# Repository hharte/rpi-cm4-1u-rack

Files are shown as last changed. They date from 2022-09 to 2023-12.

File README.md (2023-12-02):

# Raspberry Pi Compute Module 4 1U Rackmount Enclosure

# Introduction

This project consists of a [Mini-ITX](https://en.wikipedia.org/wiki/Mini-ITX) adapter and I/O plate to mount the [Raspberry Pi Compute Module 4 I/O board](https://www.raspberrypi.com/products/compute-module-4-io-board/) into the [iStarUSA D-118V2-ITX-DT 1U rackmount enclosure](https://www.amazon.com/iStarUSA-Compact-Desktop-mini-ITX-D-118V2-ITX-DT/dp/B0053YKPLM/).  Neither the I/O plate nor the adapter are strictly ITX-compliant; however they are a good fit for the iStarUSA enclosure.

The I/O plate includes openings for all CM4 I/O board connectors; however, the user may wish to remove the 12VDC barrel connector and/or the MicroSD card opening, depending on the use case.

[FreeCAD 0.20](https://www.freecad.org/) `FCstd` files are provided for easy modification.

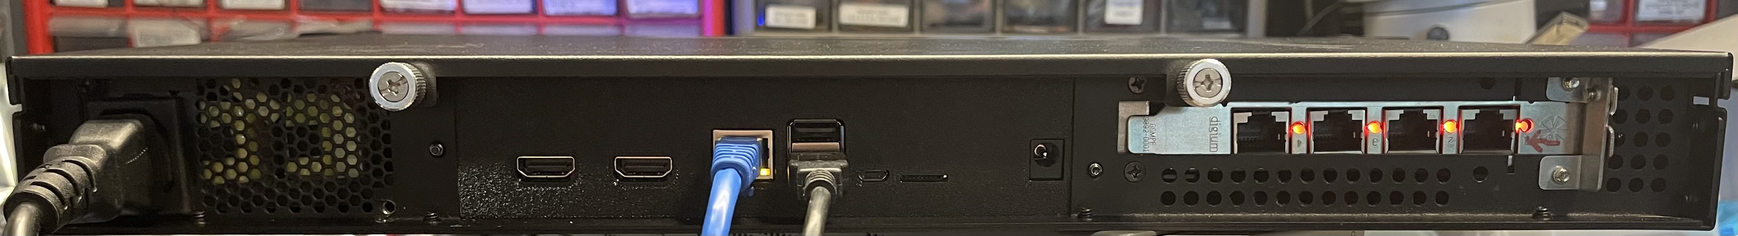
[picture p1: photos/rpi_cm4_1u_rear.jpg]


The `.stl` files for 3D-printing are also available on [Thingiverse](https://www.thingiverse.com/thing:5500278).

# Parts / Tools Required

## Required

* Four M2.5 screws.
* Four Female-Male M2.5 hex standoffs, 5 mm in length, with threads protruding 3 mm.
* M2.5 tap (alternatively, you can drill the four holes for the M2.5 standoffs slightly for an interference fit with the standoffs.)

Standard motherboard screws are used to attach the I/O plate to the iStarUSA chassis.

## Optional

1U Power Supply: [FSP Mini ITX Solution/Flex ATX 300W](https://www.amazon.com/dp/B08J2NDBWY) and an [ATX bridge adapter](https://www.amazon.com/SDTC-Tech-Starter-Without-Motherboard/dp/B07X9SVB5K).

One or two 40mm fans: [Noctura NF-A4x20](https://www.amazon.com/dp/B071W93333)

[PCIe Extender Cable](https://www.amazon.com/dp/B07TBLRZYJ)

If using an ITX/ATX power supply, it is necessary to buy or build an [ATX bridge adapter](https://www.amazon.com/SDTC-Tech-Starter-Without-Motherboard/dp/B07X9SVB5K).

# 3D Printing

Print the I/O plate with the rear face downward (stiffener ribs facing up) and use 100% infill.

The ITX adapter plate can be printed either side facing down, but I prefer to flip it over to have the nicer finish on the top.  Again 100% infill is recommended.

iStarUSA D-118V2-ITX-DT (from Monoprice [[link](https://www.monoprice.com/product?p_id=41762)]) 

Supports a full-height PCIe card.  Does not properly support a half-height PCIe card.  Modification is needed.

# Enclosure LEDs

### Blue Power LED

Splice a 510 ohm ⅛ watt resistor in line with the power LED (+) lead.  Plug the power LED (+) lead into CM4 J8 expansion header pin 2 (5V.)  Plug the power LED (-)  into expansion header pin 4 (GND.)

### Red HDD LED

The red HDD LED is controlled by software using GPIO22.

Splice a 330 ohm ⅛ watt resistor in line with the HDD LED (+) lead (blue.)  Plug the HDD LED (+) lead into expansion header J8 pin 15 (GPIO22.)  Plug the HDD LED (-)  into expansion header pin 17 (3.3V.)

#### Configure and turn off HDD LED

echo 22 > /sys/class/gpio/export

echo "out" > /sys/class/gpio/gpio22/direction 

echo "1" > /sys/class/gpio/gpio22/value 

#### Turn on HDD LED

echo "0" > /sys/class/gpio/gpio22/value 

# Reset Switch

The enclosure’s reset switch is connected to J1 pins 1 and 2 to disable eMMC boot when pressed.  This allows the CM4’s internal eMMC storage device to be mounted as a USB disk, if this switch is held while the system is powered on.  See [Jeff Geerling’s blog post for details](https://www.jeffgeerling.com/blog/2020/how-flash-raspberry-pi-os-compute-module-4-emmc-usbboot).

# Fans

The CM4 I/O board supports a PWM-controlled fan.  The enclosure has room for two 20mm fans.  The [Noctura NF-A4x20](https://www.amazon.com/dp/B071W93333) fans used in this project come with a Y-cable to allow two fans to be connected to the CM4 I/O board’s single fan connector.  They also come with mounting hardware and are very quiet.

To enable the fan driver when running a recent version of Raspberry Pi OS, add the following ([reference](https://github.com/raspberrypi/linux/issues/4632#issuecomment-1138400686)) to `/boot/config.txt`:

```
dtoverlay=i2c-fan,emc2301
```

To check the current fan speed, run the following as root:

```
cat /sys/class/hwmon/hwmon2/fan1_input
```

To check the current CPU temperature, run the following as root:

```
cat /sys/class/thermal/thermal_zone0/temp
```

The Noctura 

# Front Panel USB 2.0

Connect the front panel USB cables to the 2x5 header at J14 on the CM4 I/O board.  Desolder or bend pin 10 out of the way so it does not interfere with the key plug in the front panel cable connector.

# PCIe

## Bracket

The iStarUSA enclosure supports a full-height PCIe bracket.  It will not work with a half-height PCIe card without modification.

## Power

A 12VDC power supply is required when using the PCIe slot on the CM4 I/O board.

## Compatible PCIe devices

See [this list of PCIe devices](https://pipci.jeffgeerling.com/) and their current operational status with the CM4.

# Photos

## I/O Plate

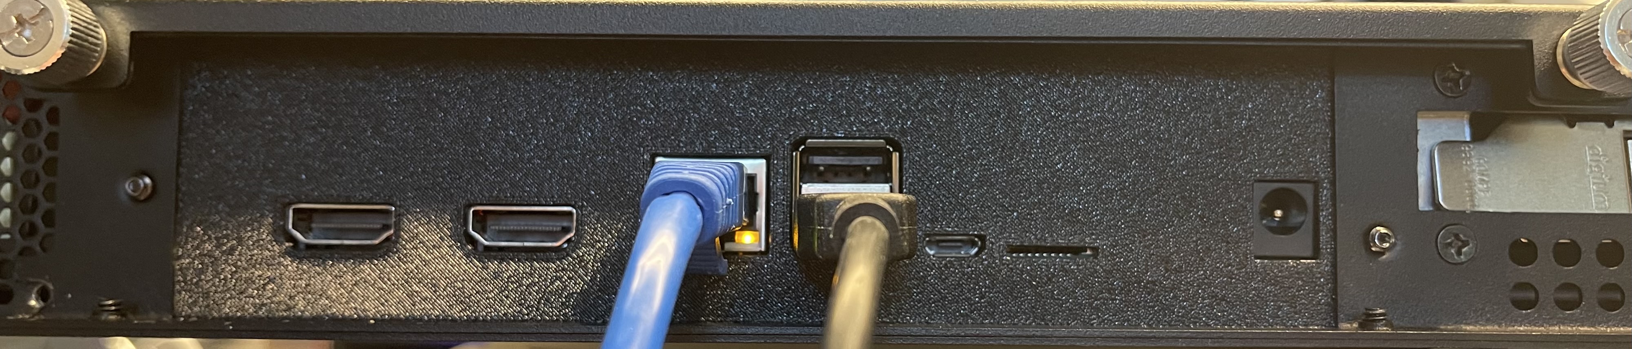
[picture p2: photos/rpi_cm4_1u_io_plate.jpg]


## Interior View

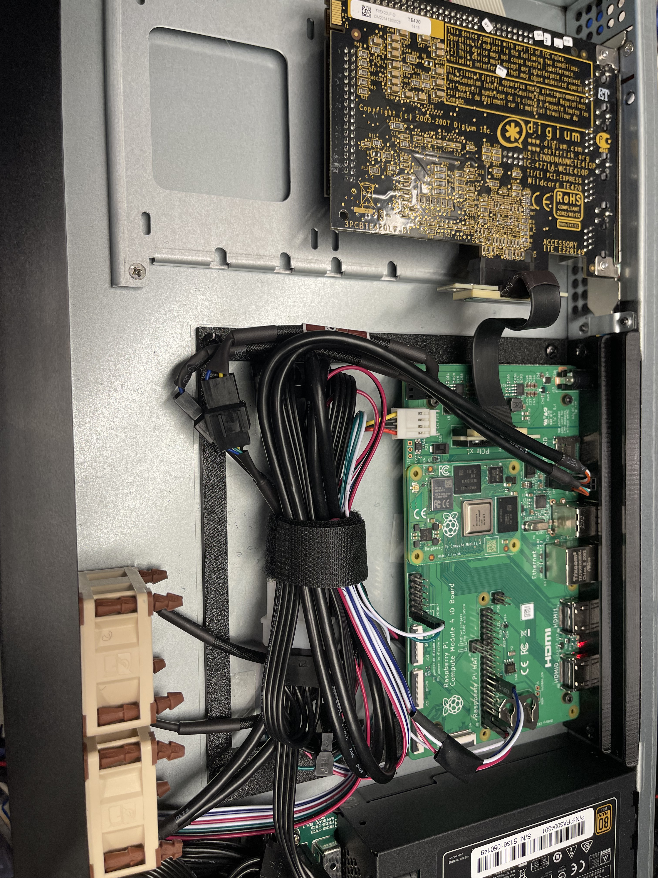
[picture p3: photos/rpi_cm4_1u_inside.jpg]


## Front Panel USB Connection

Note: Pin 10 is bent out of the way to allow the enclosure’s front panel USB header to be installed.

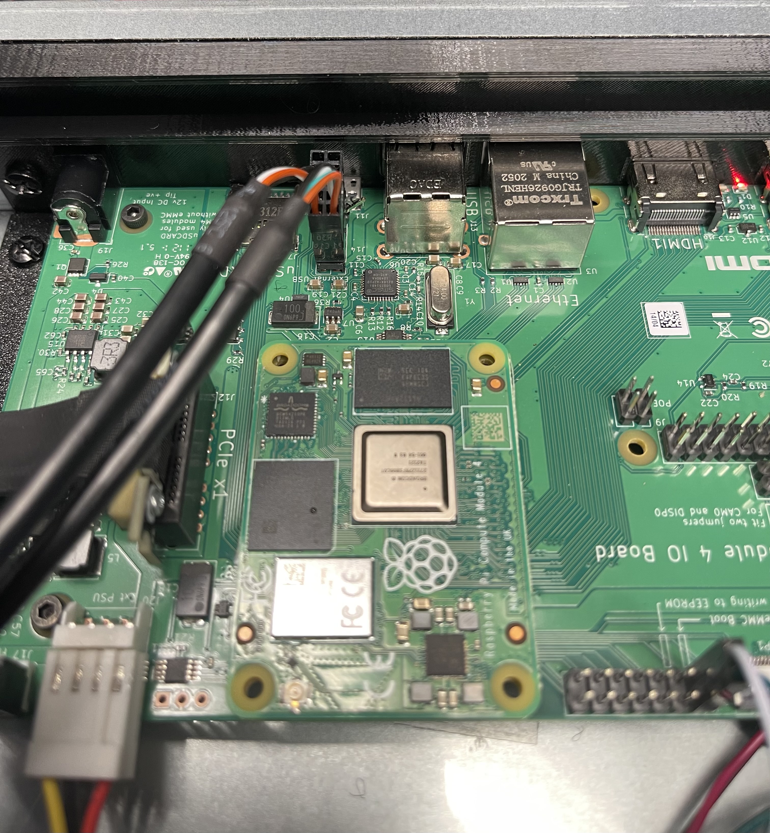
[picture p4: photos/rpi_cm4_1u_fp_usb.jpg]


# References

Raspberry Pi CM4 I/O Board ([manual](https://datasheets.raspberrypi.com/cm4io/cm4io-datasheet.pdf))

[iStarUSA D-118V2 case on Amazon](https://www.amazon.com/iStarUSA-Compact-Desktop-mini-ITX-D-118V2-ITX-DT/dp/B0053YKPLM/)

[RackChoice 1U on Amazon](https://www.amazon.com/dp/B0B3MG34D1)

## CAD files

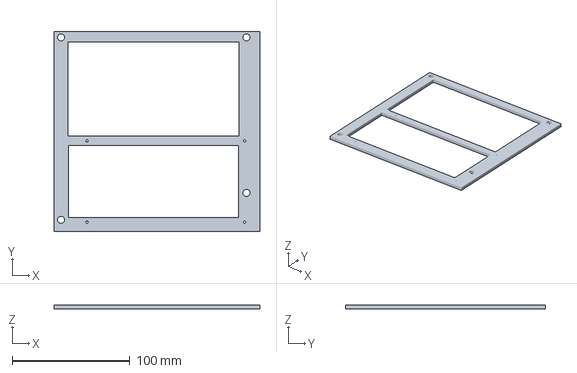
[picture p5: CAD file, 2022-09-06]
cad/mfg/RPI_CM4_ITX_Adapter_Plate.3mf
175.0 x 170.0 x 3.50 mm

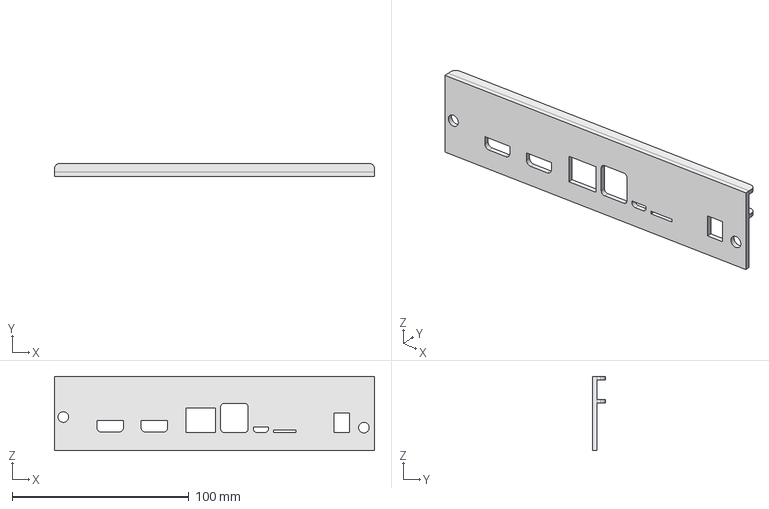
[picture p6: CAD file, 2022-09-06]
cad/RPI_CM4_IO_Plate.FCStd
181.0 x 7.50 x 42.0 mm

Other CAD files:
cad/mfg/RPI_CM4_IO_Plate.3mf
cad/RPI_CM4_ITX_Adapter_Plate.FCStd
cad/RPI_CM4_IO_Plate.stl
cad/RPI_CM4_ITX_Adapter_Plate.stl

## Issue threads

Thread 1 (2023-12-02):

Link to 1U enclosure doesn't work - product no longer available

westyd1982, 2023-12-02:
The link you have for the 1U enclosure doesn't work because Monoprice doesn't have the product any longer. Amazon has it: https://www.amazon.com/iStarUSA-Compact-Desktop-mini-ITX-D-118V2-ITX-DT/dp/B0053YKPLM/. I bought the RackChoice 1U from Amazon: https://www.amazon.com/dp/B0B3MG34D1. It appears to be the same case for $15 less.

hharte, 2023-12-02:
Thanks @westyd1982 for the links.  I updated the README to reflect the latest availability.

Take care,
Howard

westyd1982, 2023-12-03:
Howard -

I don’t know if e-mail will work, but for the USB connector, instead of bending pin 10, I used a 1/16” drill to complete the hole on the connector. Then it just plugs in.

My enclosure has three LEDs: power, network, and drive. I’m using https://github.com/mlh5599/PiLEDlights-pigpiod <https://github.com/mlh5599/PiLEDlights-pigpiod> to control the LEDs.

I built a little board for the LEDs and switches using an Adafruit Pi Hat Perma-proto board. It plugs into the 40-pin header. It connects the gpio lines through the proper resistors and has the headers for the plugs.

Thanks for documenting your project. It made it easy for me to build my own 1U NAS with the CM4 IO Board. A very nice low power backup solution for my network.

- Tom Rinehart

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

Closed 2023-12-02.

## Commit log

2022-09-06 Initial revision.
    [RPI_CM4_IO_Plate.3mf, RPI_CM4_IO_Plate.FCStd, RPI_CM4_IO_Plate.stl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]
2023-12-02 Resolve issue #1, update case link to Amazon.
    The iStarUSA D-118V2 case is no longer available from MonoPrice.
    Add Amazon link for the case, and also a similar (possibly the same)
    case that is slightly cheaper.
    Thanks @westyd1982
